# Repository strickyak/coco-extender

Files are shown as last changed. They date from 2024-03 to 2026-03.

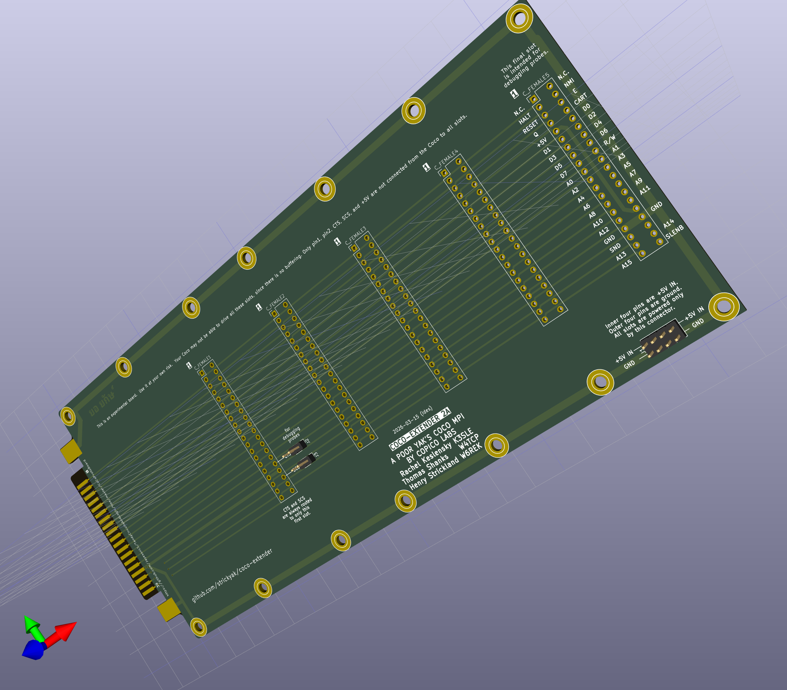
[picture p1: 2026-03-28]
poor-yaks-mpi-2a/poor-yaks-mpi-2a.3d.png

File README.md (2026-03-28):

# coco-extender
Extension cards for Radio Shack Color Computers

Directory poor-yaks-mpi-2a is a simple PCB with 4 or 5 edgecard
sockets.  It does no buffering nor switching of signals,
so it is more like a "Y Cable" than like a real MPI.
But I find it useful!   See the README.md in that directory.

Directory coco-extender-v1/ is the older CoCoExBo by Rachel Keslensky.  It has
one Edgecard Female and one 40-pin header suitable for a 40-wire ribbon
cable, in addition to the edgecard male that inserts into the CoCo slot.
(Probably you should use the poor-yaks-mpi-2a/ PCB above, instead.)

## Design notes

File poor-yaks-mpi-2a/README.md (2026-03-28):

# "Coco-Extender 2A" a.k.a. "A POOR YAK'S MPI"

NOTA BENE: This is not a consumer-friendly MPI.  It is more of an
experimenter's tool.  PLEASE READ THIS ENTIRE FILE so you will understand
the limitations!

This multi-slot Coco Extender is roughly a simple "Y cable" that brings
all the signals directly from the Coco's edgecard socket to up to five
edgecard slots.

All signals are ganged directly to the same pin number on all sockets,
with these exceptions:

* Pins 1 and 2, reserved for +12V and -12V, are never connected
    to anything.

* The +5V from the Coco is not wired to anything. 
    (Instead, you must provide an external +5VDC supply
    to the small connector in the corner, to power the
    +5V pins on the edgecard sockets.)

* /CTS and /SCS (that is, the active-low enables for Cartrige
    Rom and Floppy Disk controller) are wired to the first
    connector, and not to any others.   The others get +5V
    instead, the inactive voltage for these signals.

There is no buffering on this extender, so you may not be able to use
all the slots, without putting too large a load on your poor little Coco.

The Fifth slot could be used for a fifth edgecard socket, but I like to
solder pin headers on it, and use it as debug signals for an oscilloscope.

The 8-pin header in the lower right corner of the board is where you
must provide +5VDC from an external supply.  That will be the +5V to
all of the edgecard sockets (but not to the Coco itself!).  Here is
an example 3A 5VDC supply that is under $10 on Amazon that comes
with a plug adapter that is easy to wire to the power pin headers:
https://www.amazon.com/MTYTOT-Adapter-100V-240V-Converter-Security/dp/B0BV64MHY6/

This schematic has no surface mount components and needs no assembly by
the PCB maker.  But you'll have to get your own 40-pin edgecard sockets
and your own pin headers, and solder them on.

You can get 40-pin edgecard sockets from here:
https://www.amazon.com/dp/B0BPP35SRC

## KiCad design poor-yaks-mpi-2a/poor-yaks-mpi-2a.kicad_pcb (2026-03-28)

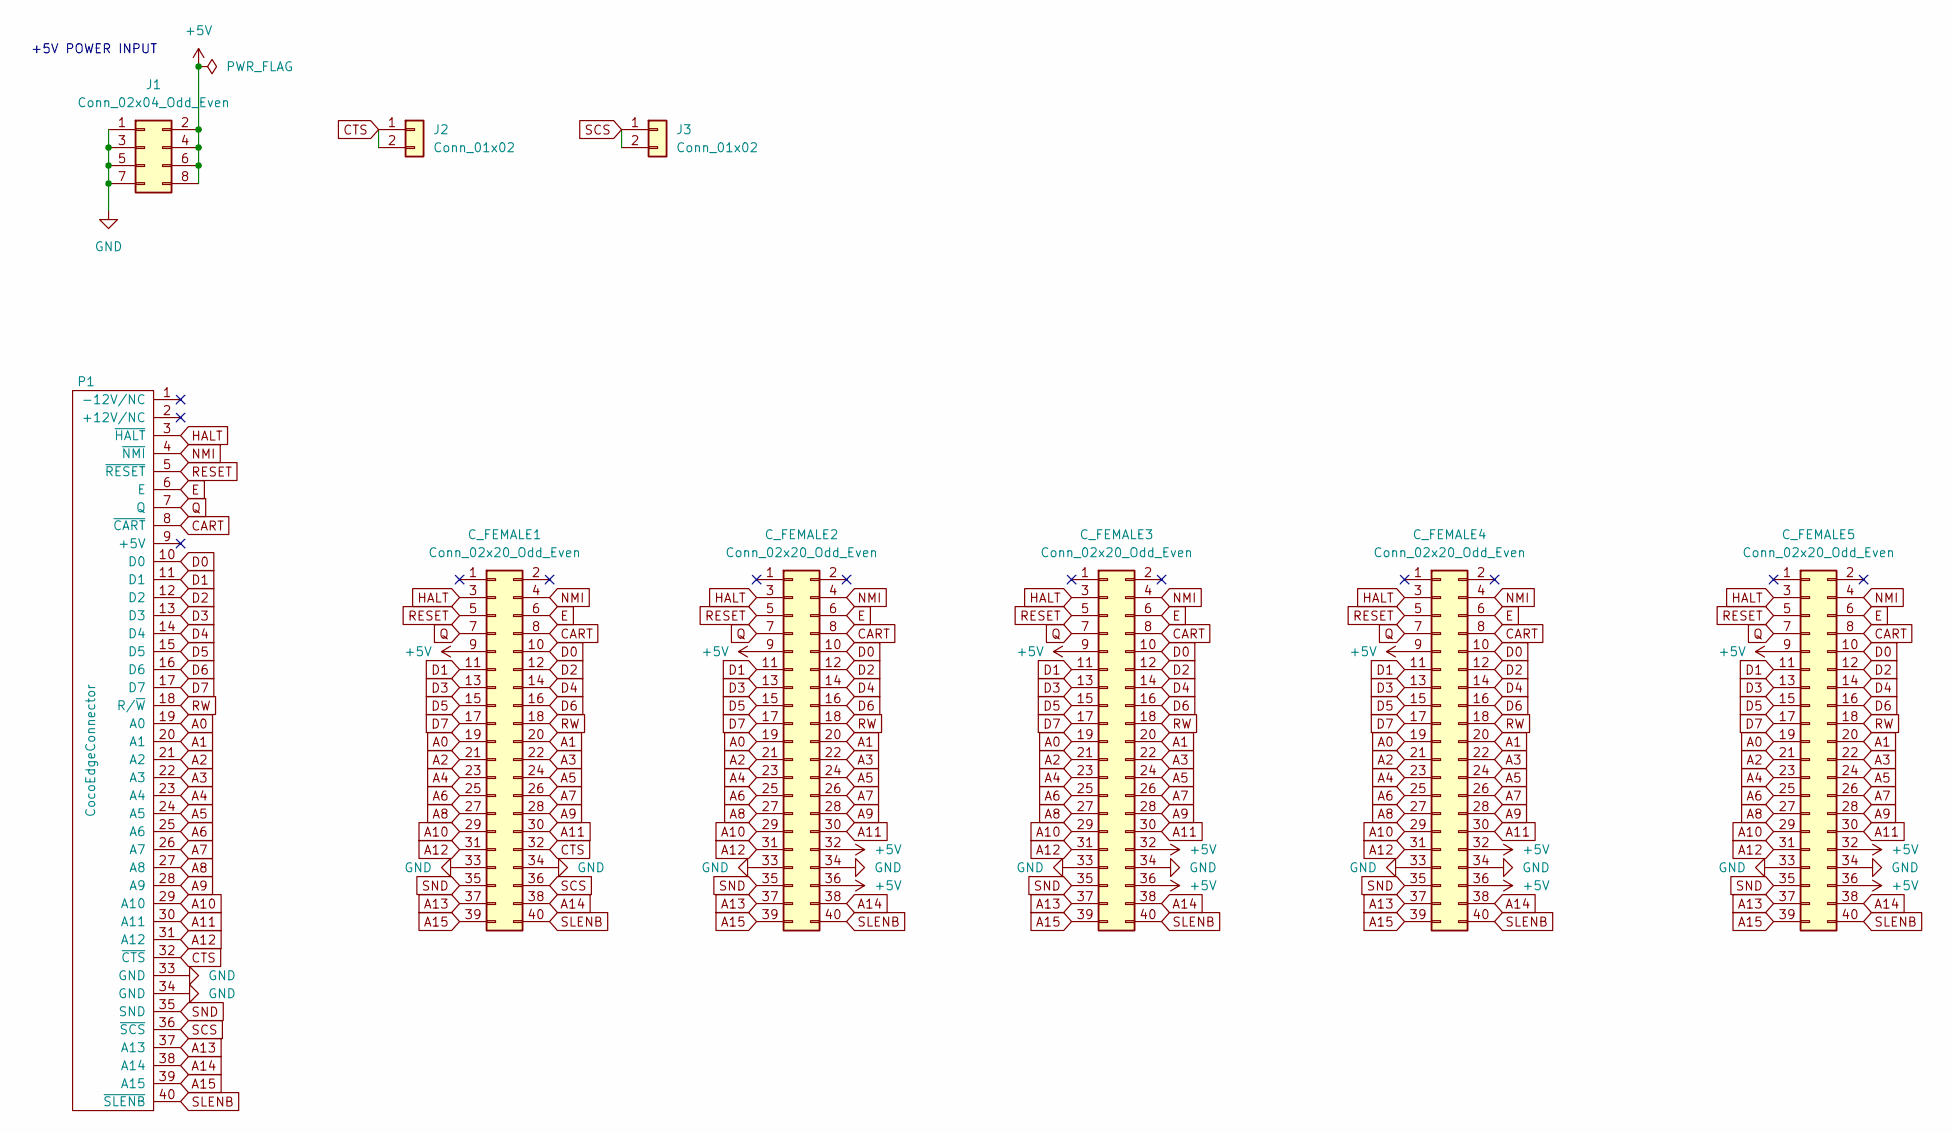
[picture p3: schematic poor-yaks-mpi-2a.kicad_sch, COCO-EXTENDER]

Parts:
C_FEMALE1, C_FEMALE2, C_FEMALE3, C_FEMALE4, C_FEMALE5: Conn_02x20_Odd_Even; Coco_Card_Female
J1: Conn_02x04_Odd_Even; PinHeader_2x04_P2.54mm_Vertical
J2, J3: Conn_01x02; PinHeader_1x02_P2.54mm_Vertical
P1: CocoEdgeConnector; CocoCardEdgeCocoMIDI

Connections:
+5V: C_FEMALE1.9, C_FEMALE2.9, C_FEMALE2.32, C_FEMALE2.36, C_FEMALE3.9, C_FEMALE3.32, C_FEMALE3.36, C_FEMALE4.9, C_FEMALE4.32, C_FEMALE4.36, C_FEMALE5.9, C_FEMALE5.32, C_FEMALE5.36, J1.2, J1.4, J1.6, J1.8
A0: C_FEMALE1.19, C_FEMALE2.19, C_FEMALE3.19, C_FEMALE4.19, C_FEMALE5.19, P1.19 (A0)
A1: C_FEMALE1.20, C_FEMALE2.20, C_FEMALE3.20, C_FEMALE4.20, C_FEMALE5.20, P1.20 (A1)
A2: C_FEMALE1.21, C_FEMALE2.21, C_FEMALE3.21, C_FEMALE4.21, C_FEMALE5.21, P1.21 (A2)
A3: C_FEMALE1.22, C_FEMALE2.22, C_FEMALE3.22, C_FEMALE4.22, C_FEMALE5.22, P1.22 (A3)
A4: C_FEMALE1.23, C_FEMALE2.23, C_FEMALE3.23, C_FEMALE4.23, C_FEMALE5.23, P1.23 (A4)
A5: C_FEMALE1.24, C_FEMALE2.24, C_FEMALE3.24, C_FEMALE4.24, C_FEMALE5.24, P1.24 (A5)
A6: C_FEMALE1.25, C_FEMALE2.25, C_FEMALE3.25, C_FEMALE4.25, C_FEMALE5.25, P1.25 (A6)
A7: C_FEMALE1.26, C_FEMALE2.26, C_FEMALE3.26, C_FEMALE4.26, C_FEMALE5.26, P1.26 (A7)
A8: C_FEMALE1.27, C_FEMALE2.27, C_FEMALE3.27, C_FEMALE4.27, C_FEMALE5.27, P1.27 (A8)
A9: C_FEMALE1.28, C_FEMALE2.28, C_FEMALE3.28, C_FEMALE4.28, C_FEMALE5.28, P1.28 (A9)
A10: C_FEMALE1.29, C_FEMALE2.29, C_FEMALE3.29, C_FEMALE4.29, C_FEMALE5.29, P1.29 (A10)
A11: C_FEMALE1.30, C_FEMALE2.30, C_FEMALE3.30, C_FEMALE4.30, C_FEMALE5.30, P1.30 (A11)
A12: C_FEMALE1.31, C_FEMALE2.31, C_FEMALE3.31, C_FEMALE4.31, C_FEMALE5.31, P1.31 (A12)
A13: C_FEMALE1.37, C_FEMALE2.37, C_FEMALE3.37, C_FEMALE4.37, C_FEMALE5.37, P1.37 (A13)
A14: C_FEMALE1.38, C_FEMALE2.38, C_FEMALE3.38, C_FEMALE4.38, C_FEMALE5.38, P1.38 (A14)
A15: C_FEMALE1.39, C_FEMALE2.39, C_FEMALE3.39, C_FEMALE4.39, C_FEMALE5.39, P1.39 (A15)
CART: C_FEMALE1.8, C_FEMALE2.8, C_FEMALE3.8, C_FEMALE4.8, C_FEMALE5.8, P1.8 (~CART)
CTS: C_FEMALE1.32, J2.1, J2.2, P1.32 (~CTS)
D0: C_FEMALE1.10, C_FEMALE2.10, C_FEMALE3.10, C_FEMALE4.10, C_FEMALE5.10, P1.10 (D0)
D1: C_FEMALE1.11, C_FEMALE2.11, C_FEMALE3.11, C_FEMALE4.11, C_FEMALE5.11, P1.11 (D1)
D2: C_FEMALE1.12, C_FEMALE2.12, C_FEMALE3.12, C_FEMALE4.12, C_FEMALE5.12, P1.12 (D2)
D3: C_FEMALE1.13, C_FEMALE2.13, C_FEMALE3.13, C_FEMALE4.13, C_FEMALE5.13, P1.13 (D3)
D4: C_FEMALE1.14, C_FEMALE2.14, C_FEMALE3.14, C_FEMALE4.14, C_FEMALE5.14, P1.14 (D4)
D5: C_FEMALE1.15, C_FEMALE2.15, C_FEMALE3.15, C_FEMALE4.15, C_FEMALE5.15, P1.15 (D5)
D6: C_FEMALE1.16, C_FEMALE2.16, C_FEMALE3.16, C_FEMALE4.16, C_FEMALE5.16, P1.16 (D6)
D7: C_FEMALE1.17, C_FEMALE2.17, C_FEMALE3.17, C_FEMALE4.17, C_FEMALE5.17, P1.17 (D7)
E: C_FEMALE1.6, C_FEMALE2.6, C_FEMALE3.6, C_FEMALE4.6, C_FEMALE5.6, P1.6 (E)
GND: C_FEMALE1.33, C_FEMALE1.34, C_FEMALE2.33, C_FEMALE2.34, C_FEMALE3.33, C_FEMALE3.34, C_FEMALE4.33, C_FEMALE4.34, C_FEMALE5.33, C_FEMALE5.34, J1.1, J1.3, J1.5, J1.7, P1.33 (GND), P1.34 (GND)
HALT: C_FEMALE1.3, C_FEMALE2.3, C_FEMALE3.3, C_FEMALE4.3, C_FEMALE5.3, P1.3 (~HALT)
NMI: C_FEMALE1.4, C_FEMALE2.4, C_FEMALE3.4, C_FEMALE4.4, C_FEMALE5.4, P1.4 (~NMI)
Q: C_FEMALE1.7, C_FEMALE2.7, C_FEMALE3.7, C_FEMALE4.7, C_FEMALE5.7, P1.7 (Q)
RESET: C_FEMALE1.5, C_FEMALE2.5, C_FEMALE3.5, C_FEMALE4.5, C_FEMALE5.5, P1.5 (~RESET)
RW: C_FEMALE1.18, C_FEMALE2.18, C_FEMALE3.18, C_FEMALE4.18, C_FEMALE5.18, P1.18 (R/~W)
SCS: C_FEMALE1.36, J3.1, J3.2, P1.36 (~SCS)
SLENB: C_FEMALE1.40, C_FEMALE2.40, C_FEMALE3.40, C_FEMALE4.40, C_FEMALE5.40, P1.40 (~SLENB)
SND: C_FEMALE1.35, C_FEMALE2.35, C_FEMALE3.35, C_FEMALE4.35, C_FEMALE5.35, P1.35 (SND)

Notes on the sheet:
+5V POWER INPUT

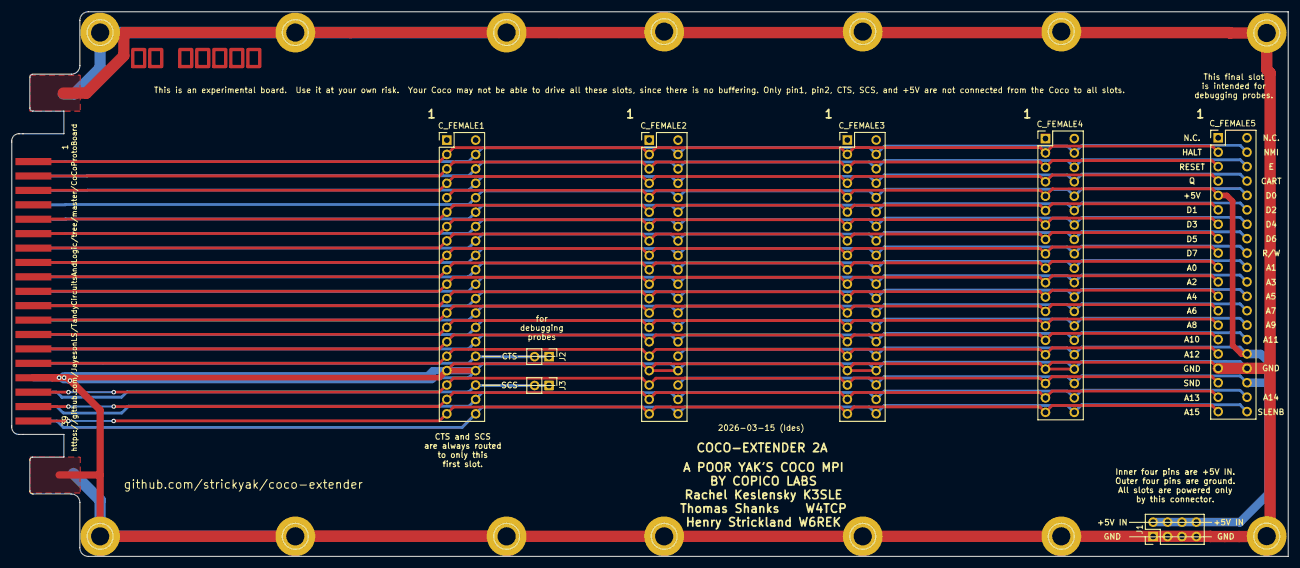
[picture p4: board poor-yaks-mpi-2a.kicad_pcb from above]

Board: 2 copper layers, 225.0 x 96.0 mm, 9 parts (0 on the bottom side), 37 nets.

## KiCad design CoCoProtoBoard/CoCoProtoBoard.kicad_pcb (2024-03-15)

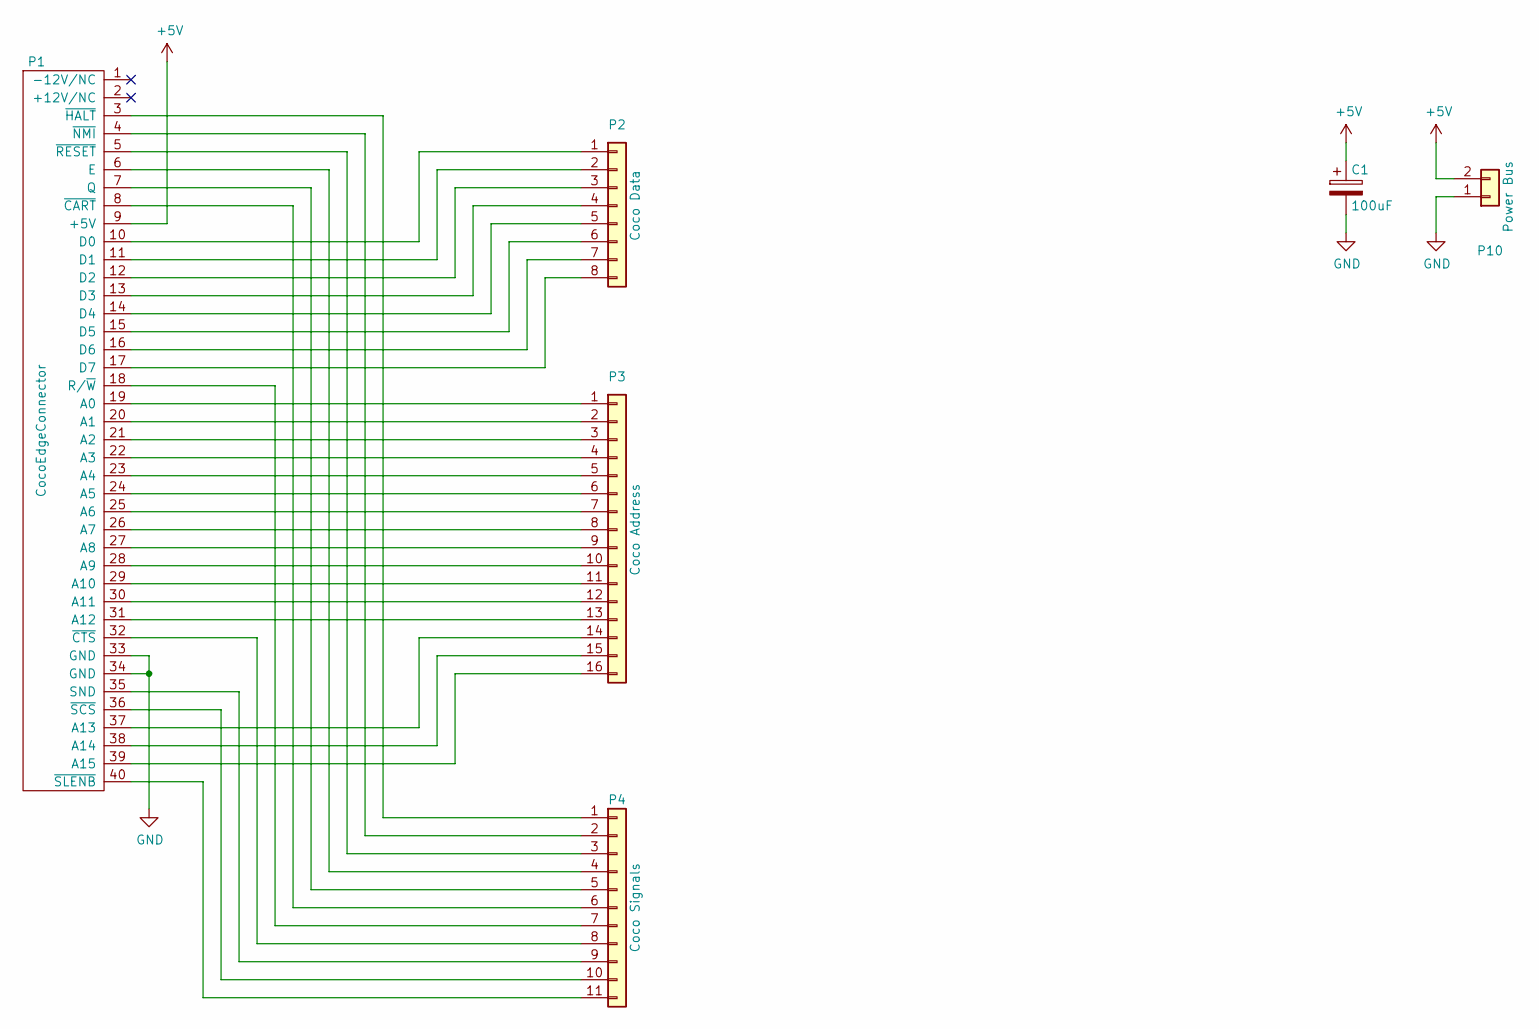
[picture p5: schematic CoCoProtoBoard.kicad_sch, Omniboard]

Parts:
C1: 100uF; C_Radial_D7.5_L11.2_P2.5
P1: CocoEdgeConnector; CocoCardEdge
P2: Coco Data; DIP-16_W7.62mm
P3: Coco Address; DIP-32_W15.24mm
P4: Coco Signals; DIP-22_W10.16mm
P10: Power Bus; DIP-16_W7.62mm

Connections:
+5V: C1.1, P1.9 (+5V), P10.2
unnamed: P1.3 (~HALT), P4.1
unnamed: P1.4 (~NMI), P4.2
unnamed: P1.5 (~RESET), P4.3
unnamed: P1.6 (E), P4.4
unnamed: P1.7 (Q), P4.5
unnamed: P1.8 (~CART), P4.6
unnamed: P1.10 (D0), P2.1
unnamed: P1.11 (D1), P2.2
unnamed: P1.12 (D2), P2.3
unnamed: P1.13 (D3), P2.4
unnamed: P1.14 (D4), P2.5
unnamed: P1.15 (D5), P2.6
unnamed: P1.16 (D6), P2.7
unnamed: P1.17 (D7), P2.8
unnamed: P1.18 (R/~W), P4.7
unnamed: P1.19 (A0), P3.1
unnamed: P1.20 (A1), P3.2
unnamed: P1.21 (A2), P3.3
unnamed: P1.22 (A3), P3.4
unnamed: P1.23 (A4), P3.5
unnamed: P1.24 (A5), P3.6
unnamed: P1.25 (A6), P3.7
unnamed: P1.26 (A7), P3.8
unnamed: P1.27 (A8), P3.9
unnamed: P1.28 (A9), P3.10
unnamed: P1.29 (A10), P3.11
unnamed: P1.30 (A11), P3.12
unnamed: P1.31 (A12), P3.13
unnamed: P1.32 (~CTS), P4.8
unnamed: P1.35 (SND), P4.9
unnamed: P1.36 (~SCS), P4.10
unnamed: P1.37 (A13), P3.14
unnamed: P1.38 (A14), P3.15
unnamed: P1.39 (A15), P3.16
unnamed: P1.40 (~SLENB), P4.11

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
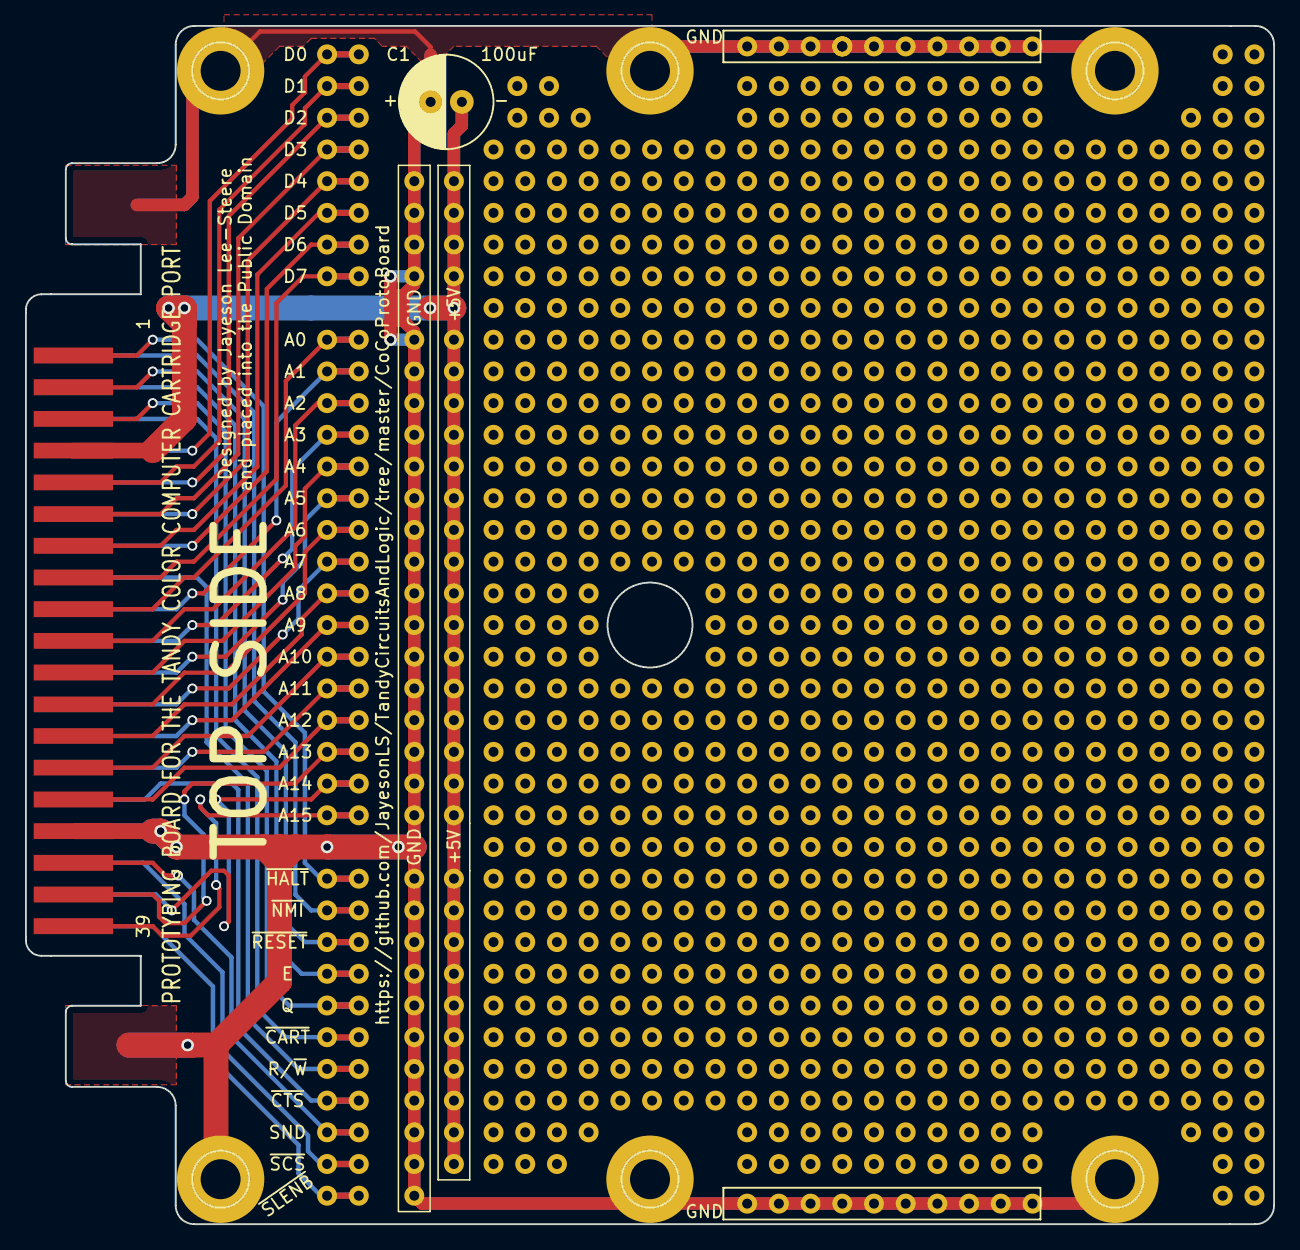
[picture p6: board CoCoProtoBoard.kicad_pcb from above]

Board: 2 copper layers, 100.0 x 96.0 mm, 6 parts (0 on the bottom side), 37 nets.

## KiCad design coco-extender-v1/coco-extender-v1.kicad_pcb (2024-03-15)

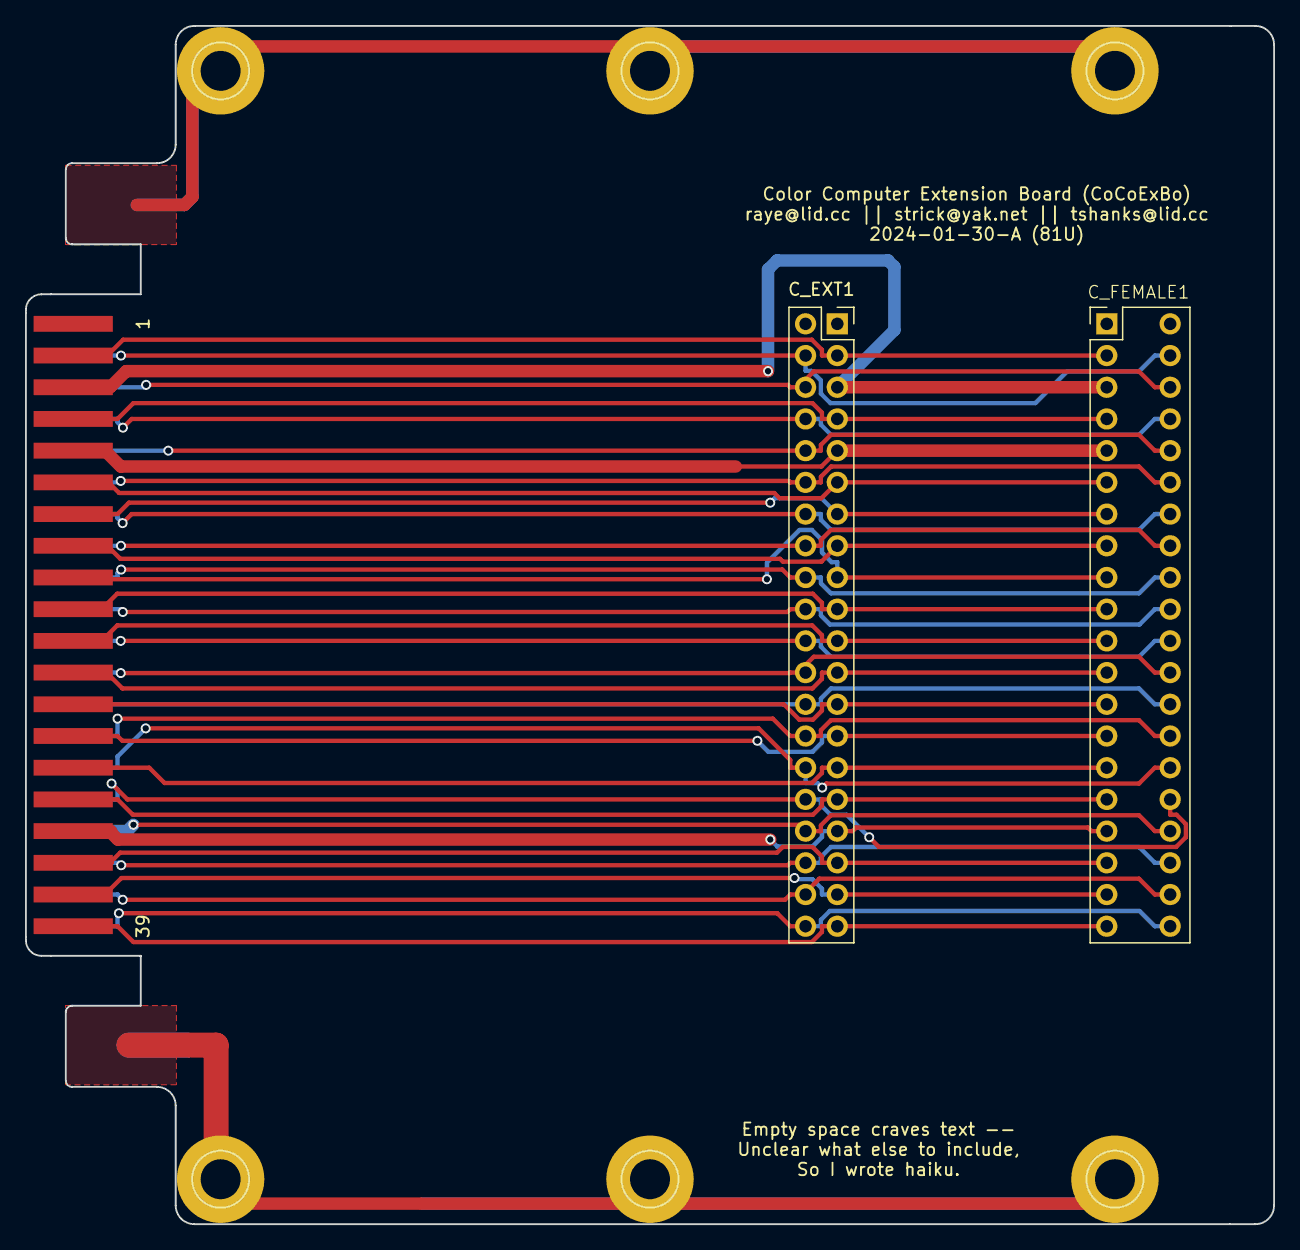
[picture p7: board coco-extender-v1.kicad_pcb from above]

Board: 2 copper layers, 100.0 x 96.0 mm, 9 parts (0 on the bottom side), 39 nets.

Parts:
CMALE1: Conn_02x20_Odd_Even; CocoCardEdge
C_EXT1: Conn_02x20_Odd_Even; PinSocket_2x20_P2.54mm_Vertical
C_FEMALE1: Conn_02x20_Odd_Even; Coco_Card_Female
GND1, GND2, GND3, GND4, GND5, GND6: 1pin

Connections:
/a3: CMALE1.3, C_EXT1.3, C_FEMALE1.3
/a4: CMALE1.4, C_EXT1.4, C_FEMALE1.4
/a5: CMALE1.5, C_EXT1.5, C_FEMALE1.5
/a6: CMALE1.6, C_EXT1.6, C_FEMALE1.6
/a7: CMALE1.7, C_EXT1.7, C_FEMALE1.7
/a8: CMALE1.8, C_EXT1.8, C_FEMALE1.8
/a9: CMALE1.9, C_EXT1.9, C_FEMALE1.9
/a10: CMALE1.10, C_EXT1.10, C_FEMALE1.10
/a11: CMALE1.11, C_EXT1.11, C_FEMALE1.11
/a12: CMALE1.12, C_EXT1.12, C_FEMALE1.12
/a13: CMALE1.13, C_EXT1.13, C_FEMALE1.13
/a14: CMALE1.14, C_EXT1.14, C_FEMALE1.14
/a15: CMALE1.15, C_EXT1.15, C_FEMALE1.15
/a16: CMALE1.16, C_EXT1.16, C_FEMALE1.16
/a17: CMALE1.17, C_EXT1.17, C_FEMALE1.17
/a18: CMALE1.18, C_EXT1.18, C_FEMALE1.18
/a19: CMALE1.19, C_EXT1.19, C_FEMALE1.19
/a20: CMALE1.20, C_EXT1.20, C_FEMALE1.20
/a21: CMALE1.21, C_EXT1.21, C_FEMALE1.21
/a22: CMALE1.22, C_EXT1.22, C_FEMALE1.22
/a23: CMALE1.23, C_EXT1.23, C_FEMALE1.23
/a24: CMALE1.24, C_EXT1.24, C_FEMALE1.24
/a25: CMALE1.25, C_EXT1.25, C_FEMALE1.25
/a26: CMALE1.26, C_EXT1.26, C_FEMALE1.26
/a27: CMALE1.27, C_EXT1.27, C_FEMALE1.27
/a28: CMALE1.28, C_EXT1.28, C_FEMALE1.28
/a29: CMALE1.29, C_EXT1.29, C_FEMALE1.29
/a30: CMALE1.30, C_EXT1.30, C_FEMALE1.30
/a31: CMALE1.31, C_EXT1.31, C_FEMALE1.31
/a32: CMALE1.32, C_EXT1.32, C_FEMALE1.32
/a33: CMALE1.33, C_EXT1.33, C_FEMALE1.33
/a34: CMALE1.34, C_EXT1.34, C_FEMALE1.34
/a35: CMALE1.35, C_EXT1.35, C_FEMALE1.35
/a36: CMALE1.36, C_EXT1.36, C_FEMALE1.36
/a37: CMALE1.37, C_EXT1.37, C_FEMALE1.37
/a38: CMALE1.38, C_EXT1.38, C_FEMALE1.38
/a39: CMALE1.39, C_EXT1.39, C_FEMALE1.39
/a40: CMALE1.40, C_EXT1.40, C_FEMALE1.40
GND: GND1.1, GND2.1, GND3.1, GND4.1, GND5.1, GND6.1

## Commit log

2024-03-15 add old coco-extender-v1
    [coco-extender-v1.kicad_pcb, coco-extender-v1.kicad_sch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]
2024-03-15 CoCoProtoBoard, the physical basis of our boards.
    [CoCoProtoBoard.kicad_pcb, CoCoProtoBoard.kicad_sch, CoCoProtoBoard.sch]
2026-03-28 coco-extender 2A (a.k.a. poor-yaks-mpi)
    [CoCoProtoBoard.sch, poor-yaks-mpi-2a.kicad_pcb, poor-yaks-mpi-2a.kicad_sch]
2026-03-28 where to get 40-pin sockets

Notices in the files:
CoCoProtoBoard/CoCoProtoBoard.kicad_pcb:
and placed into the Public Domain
